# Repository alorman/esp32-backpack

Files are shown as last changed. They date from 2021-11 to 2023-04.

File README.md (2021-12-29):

# esp32-backpack
This board is designed to couple to the back of the the [DC Metro Map](https://github.com/alorman/dc-map-500x500) and drive the LEDs.  
This daughterboard-style design is to allow for rapid iteration and testing on the driving board, while keeping the large and expensive map PCB separate.

## Images
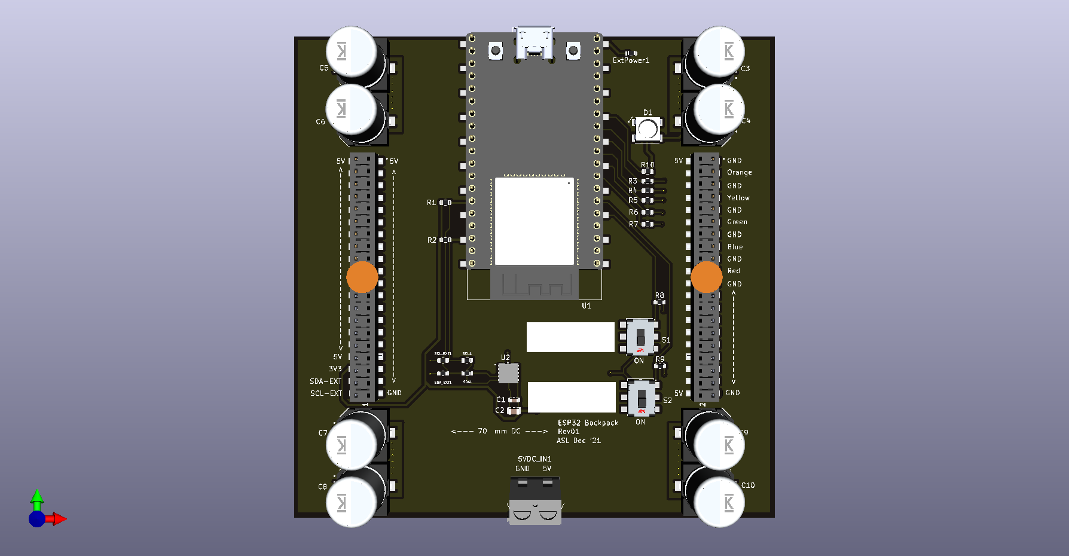
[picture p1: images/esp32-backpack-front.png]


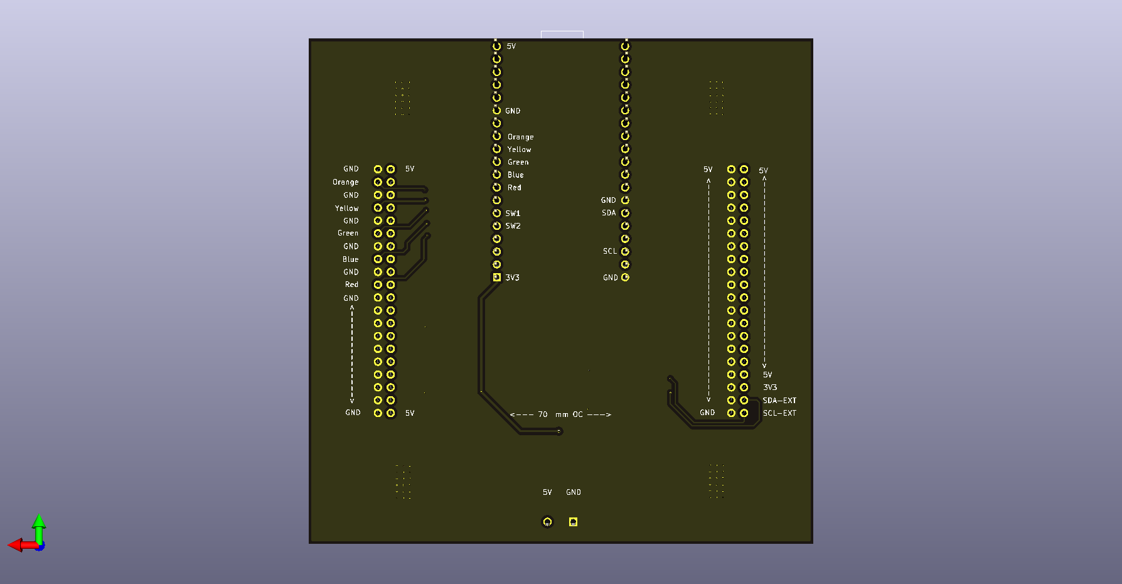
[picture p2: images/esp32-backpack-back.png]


## Schematic
[Schematic](exports/esp32-backpack-schematic.pdf)

## BOM
[Interactive BOM](exports/ibom.html)

## ESP Chipsets
ESP32 Chipsets come in about a zillion different configurations. To support the [code](https://github.com/alorman/dc_metro_map) you need a dual-core version. 

This board supports:
| Dev Kit Name | Module | Chipset | Cores | Flash | SPRAM | Notes |
|---|---|---|---|---|---|---|
| ESP32-DevKitCVE | ESP32-WROVER-E | ESP32-D0WD-V3 | 2 | 4 MB  | 8 MB  | Full Size PCB Antenna |
| ESP32-DevKitC-32E | ESP32-WROOM-32E  | ESP32-D0WD-V3 | 2 | 4 MB  | 4 MB  | Full Size PCB Antenna |
| ESP32-WROOM-32UE | ESP32­WROOM­32UE | ESP32-D0WD-V3 | 2 | 4 MB  | 4 MB  | u.FL Connector |
| HiLetgo ESP-WROOM-32 | ESP32-WROOM-32D  | ESP32-D0WD | 2 | 4 MB  | 4 MB  | NRND, Amazon |

Note: the HiLetGo (and likely other Amazonian boards) require a slight bending of the pins to fit.

## Fab Instructions
| | |
|---|---:|
| Height (mm) | 100 |
| Width (mm) | 100 |
| Layers | 2 |
| Thickness (mm) | 1.6 |
| Solder Mask | Black |
| Silkscreen | White |
| Copper Thickness  | 1 oz |
| Min Spacing | 8/8mil |
| Min Hole Size | 8mil |
| Via Process | Tented |
| Surface Treatment | HASL-Lead Free |
| Special Notes | None |

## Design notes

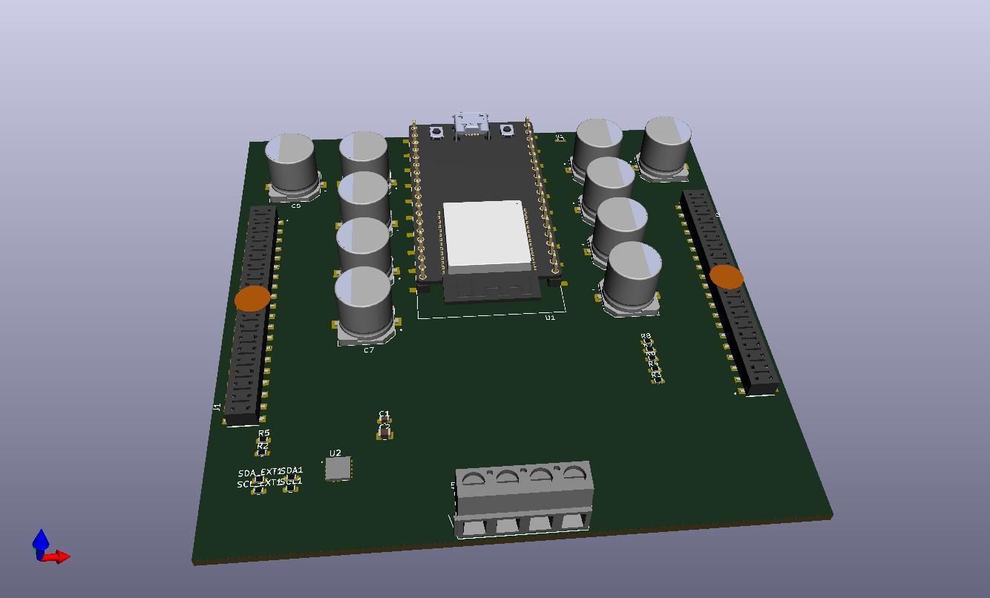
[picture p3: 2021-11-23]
ESP Backpack/ESP backpack.jpg

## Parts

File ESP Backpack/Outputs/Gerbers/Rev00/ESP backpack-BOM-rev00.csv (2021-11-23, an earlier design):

Id | Designator | Package | Quantity | Designation | Supplier and ref
1 | S1,S2 | 452403012014 | 2 | 452403012014
2 | D1 | LED_SK6812 | 1 | SK6812
3 | U1 | MODULE_ESP32-DEVKITC-32D | 1 | ESP32-DEVKITC-32D
4 | J1,J2 | SAMTEC_HLE-120-02-F-DV-BE-K | 2 | HLE-120-02-F-DV-BE-K
5 | 5VDC_IN1 | TE_282837-4 | 1 | 282837-4
6 | C6,C3,C4,C5,C7,C8,C9,C10,C11,C12,C13,C14 | CAP_EEE0JA102P | 12 | EEE0JA102P
7 | C1 | C_0603_1608Metric | 1 | 10uF
8 | C2 | C_0805_2012Metric | 1 | 0.1uF
9 | ExtPower1,SCL1,SCL_EXT1,SDA1,SDA_EXT1 | R_0603_1608Metric | 5 | 0ohm
10 | R2,R1,R8,R9 | R_0603_1608Metric | 4 | 10k
11 | R7,R6,R5,R4,R3,R10 | R_0603_1608Metric | 6 | 470
12 | U2 | XDCR_VCNL4010-GS08 | 1 | VCNL4010-GS08

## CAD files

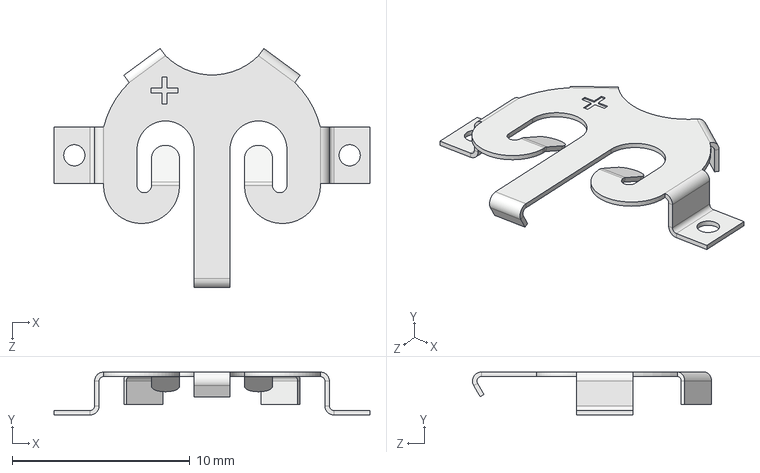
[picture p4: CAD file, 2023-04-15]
ESP Backpack/3d-Models/keystone-PN2894.STEP
17.8 x 2.42 x 13.5 mm

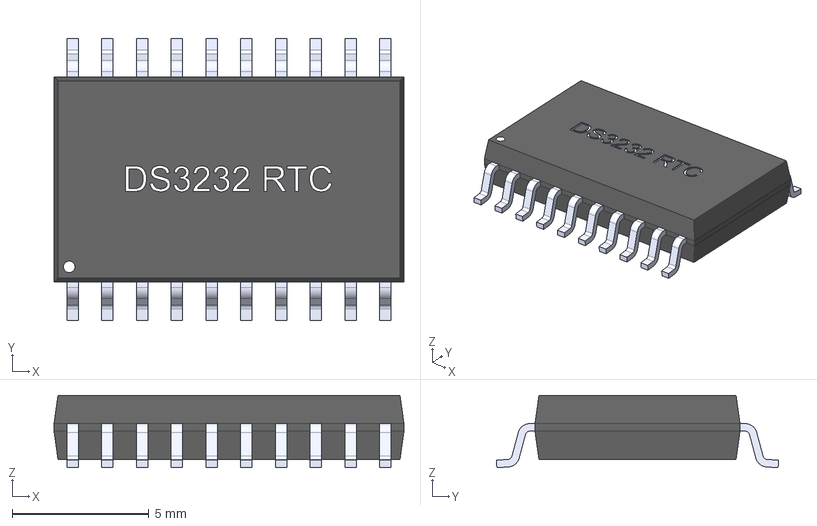
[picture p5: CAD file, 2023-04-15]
ESP Backpack/3d-Models/DS3232 RTC.step
12.8 x 10.3 x 2.65 mm
Komponente21
Komponente22
Komponente19
Komponente15
Komponente16
Komponente17
Komponente18
Komponente9
Komponente8
Komponente6
Komponente7
Komponente12
Komponente13
Komponente10
Komponente14
Komponente11
Komponente1
Komponente5
Komponente2
Komponente4
Komponente3

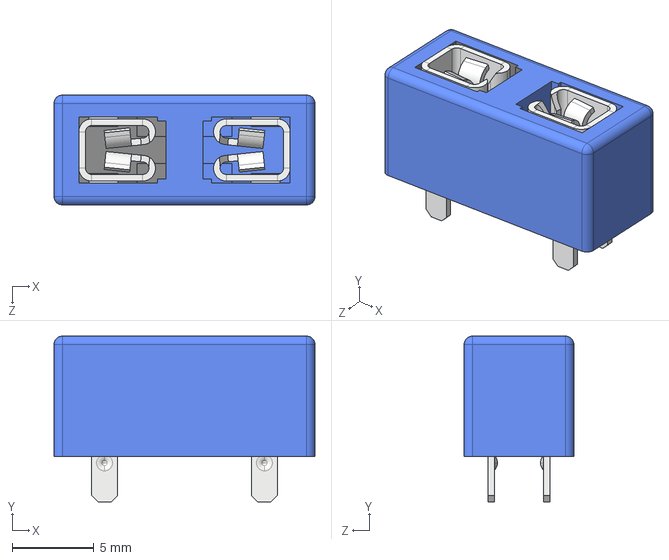
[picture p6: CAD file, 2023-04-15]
ESP Backpack/3d-Models/keystone-PN3568-15.STEP
16.0 x 10.2 x 6.73 mm

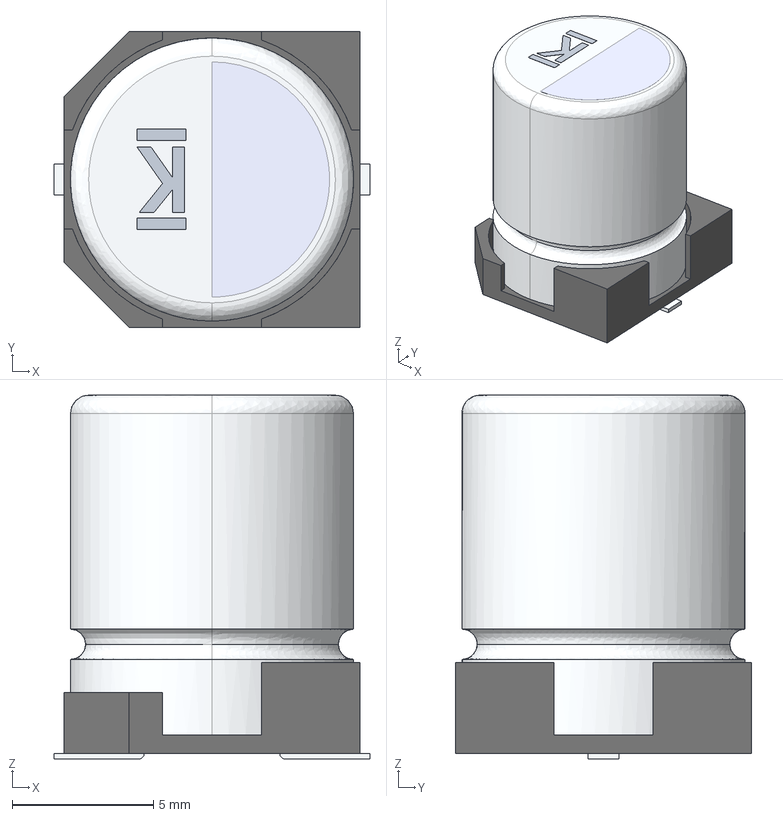
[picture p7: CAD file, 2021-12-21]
ESP Backpack/3d-Models/A765MU158M1ALAE014.step
11.2 x 10.5 x 12.9 mm

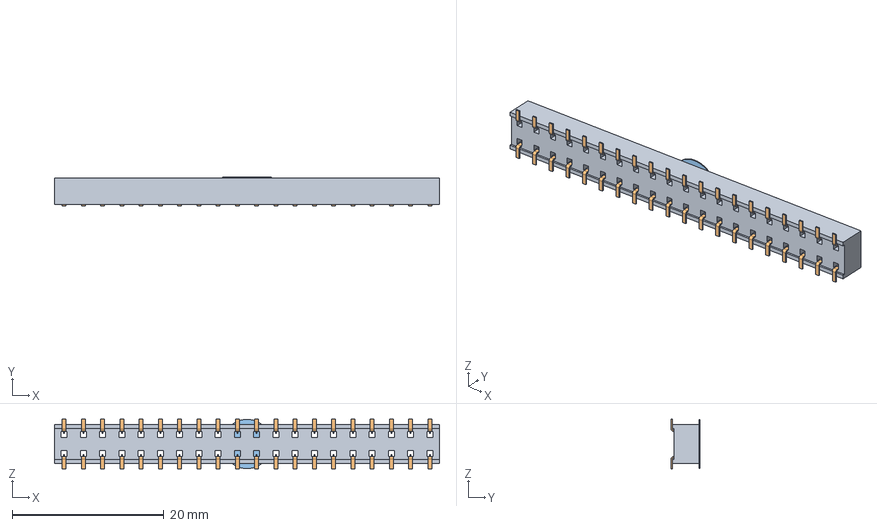
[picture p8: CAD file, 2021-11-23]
ESP Backpack/3d-Models/HLE-120-02-L-DV-K.step
50.8 x 3.78 x 6.58 mm
_HLE-120-02-DV_socket
_C-132-12-20-DV
_K-DOT-0.256-0.375-0.005_polyamide_pick

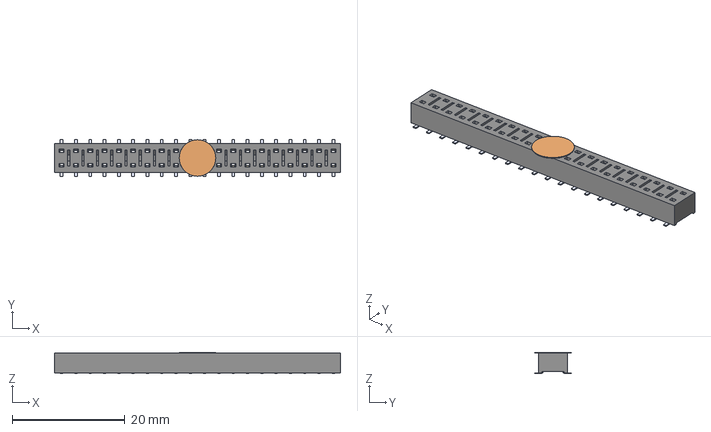
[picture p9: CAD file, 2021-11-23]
ESP Backpack/3d-Models/HLE-120-02-F-DV-BE-K--3DModel-STEP-56544.STEP
50.8 x 6.58 x 3.78 mm

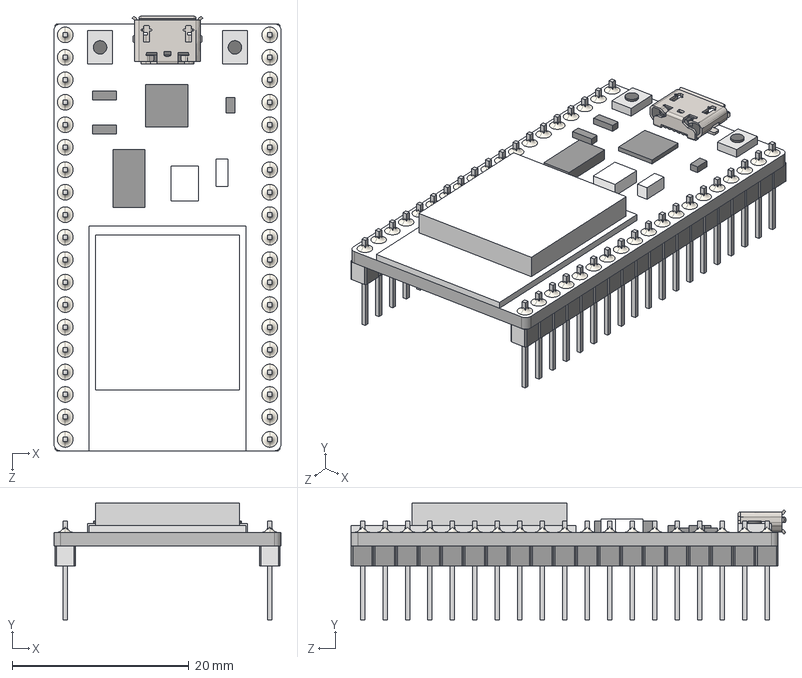
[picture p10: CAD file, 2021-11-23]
ESP Backpack/3d-Models/HiLetgo ESP32.STEP
25.7 x 13.2 x 49.1 mm
HiLetgo ESP32
molex_0473460001
PCB Button x 2
Pin Headers ESP32 x 2

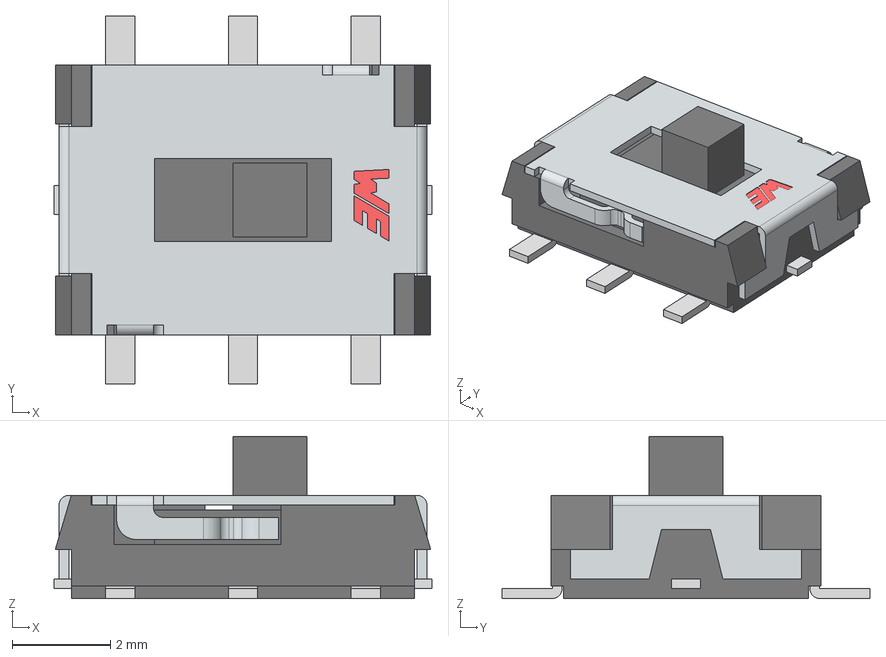
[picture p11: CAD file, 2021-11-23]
ESP Backpack/3d-Models/Download_STP_452403012014 (rev1).stp
7.70 x 7.50 x 3.30 mm
Base
Actuator
cover

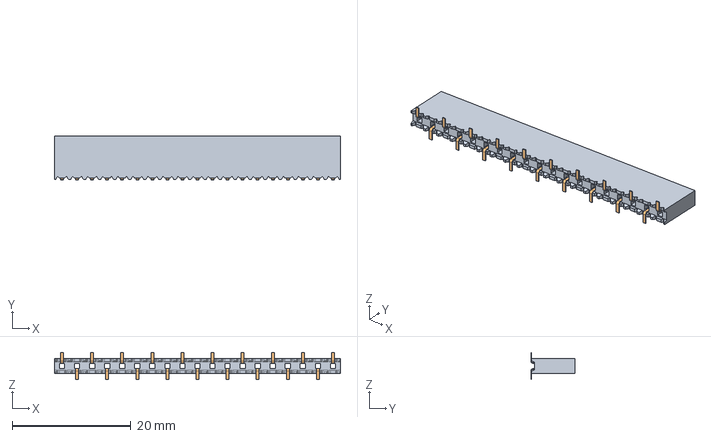
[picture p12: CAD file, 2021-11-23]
ESP Backpack/3d-Models/SSM-119-L-SV.step
48.3 x 7.49 x 4.57 mm
_SSM-119-L-SV_body
_C-95-0219

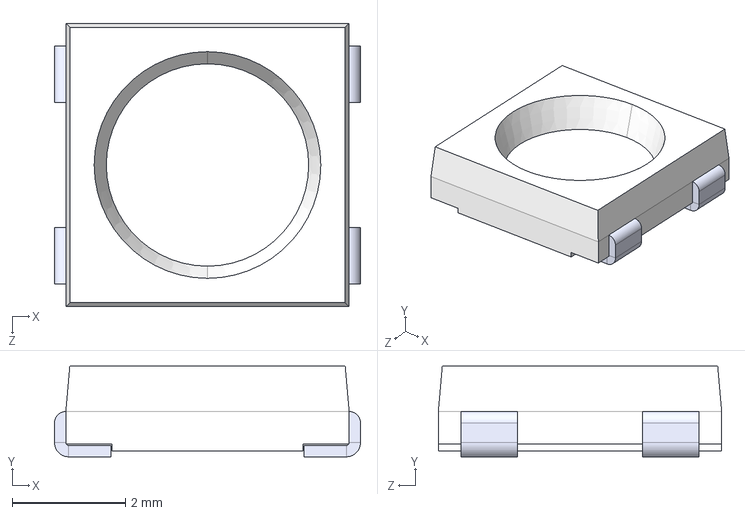
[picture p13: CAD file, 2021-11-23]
ESP Backpack/3d-Models/SK6812.step
5.40 x 1.60 x 5.00 mm

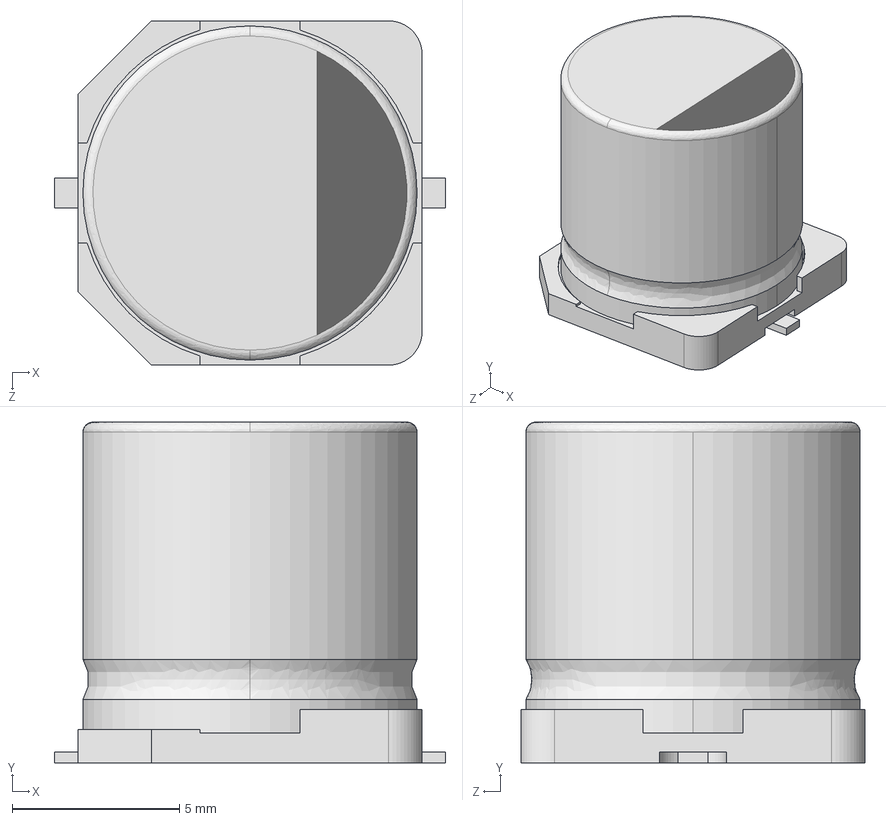
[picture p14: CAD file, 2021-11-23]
ESP Backpack/3d-Models/EEE0JA102P.step
11.7 x 10.2 x 10.3 mm

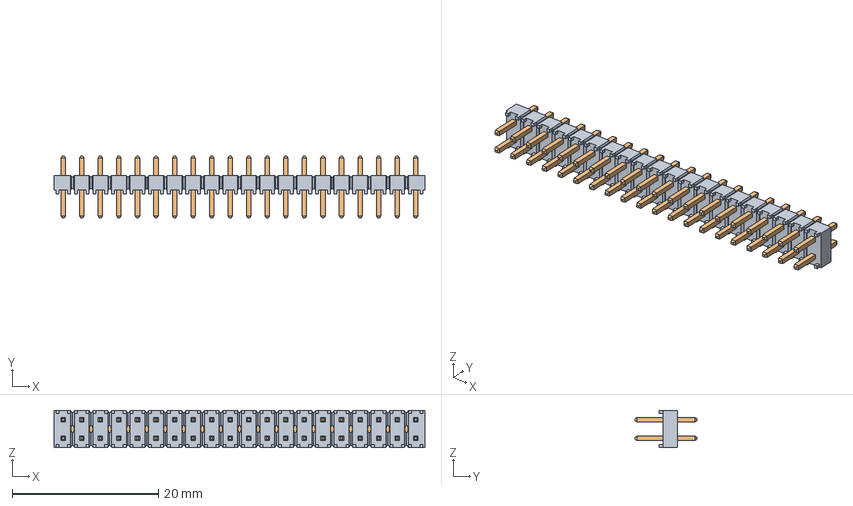
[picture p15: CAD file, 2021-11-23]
ESP Backpack/3d-Models/TSW-120-05-G-D.step
50.8 x 8.51 x 5.08 mm
_TSW-120-05-G-D_body
_T-1S6-21-TSW-1-05-20-D

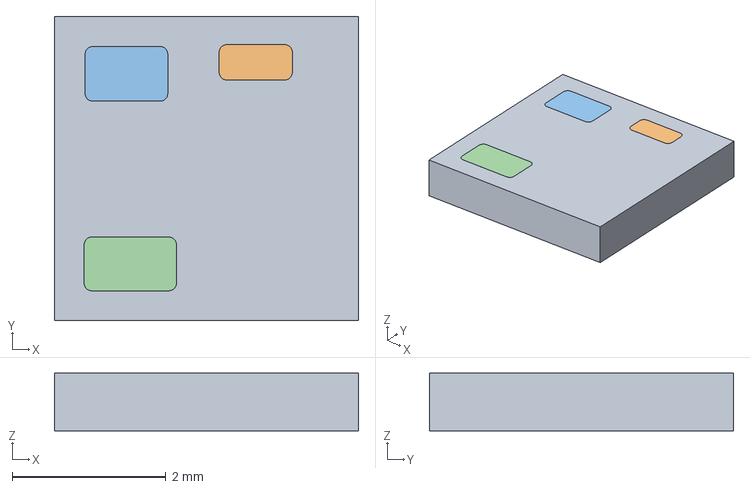
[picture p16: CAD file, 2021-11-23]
ESP Backpack/3d-Models/VCNL4010.stp
3.95 x 3.95 x 0.75 mm

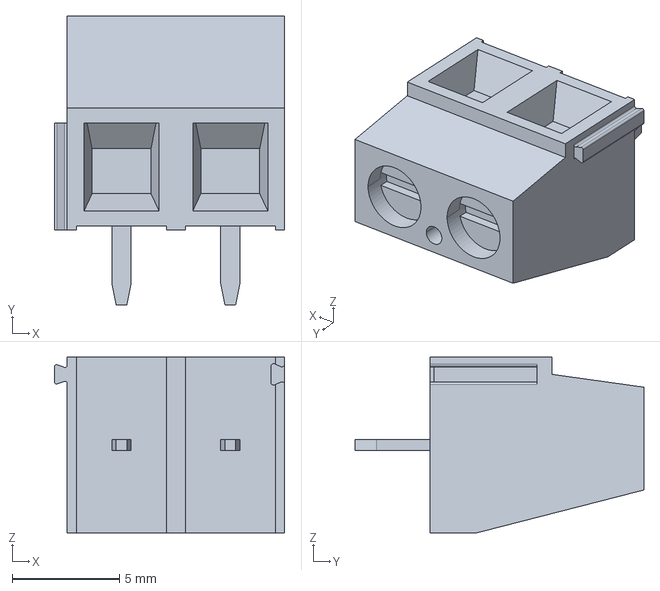
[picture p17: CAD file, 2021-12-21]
ESP Backpack/3d-Models/282837-2.step
10.8 x 13.5 x 8.20 mm

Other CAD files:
ESP Backpack/3d-Models/EEE0JA102P.stp

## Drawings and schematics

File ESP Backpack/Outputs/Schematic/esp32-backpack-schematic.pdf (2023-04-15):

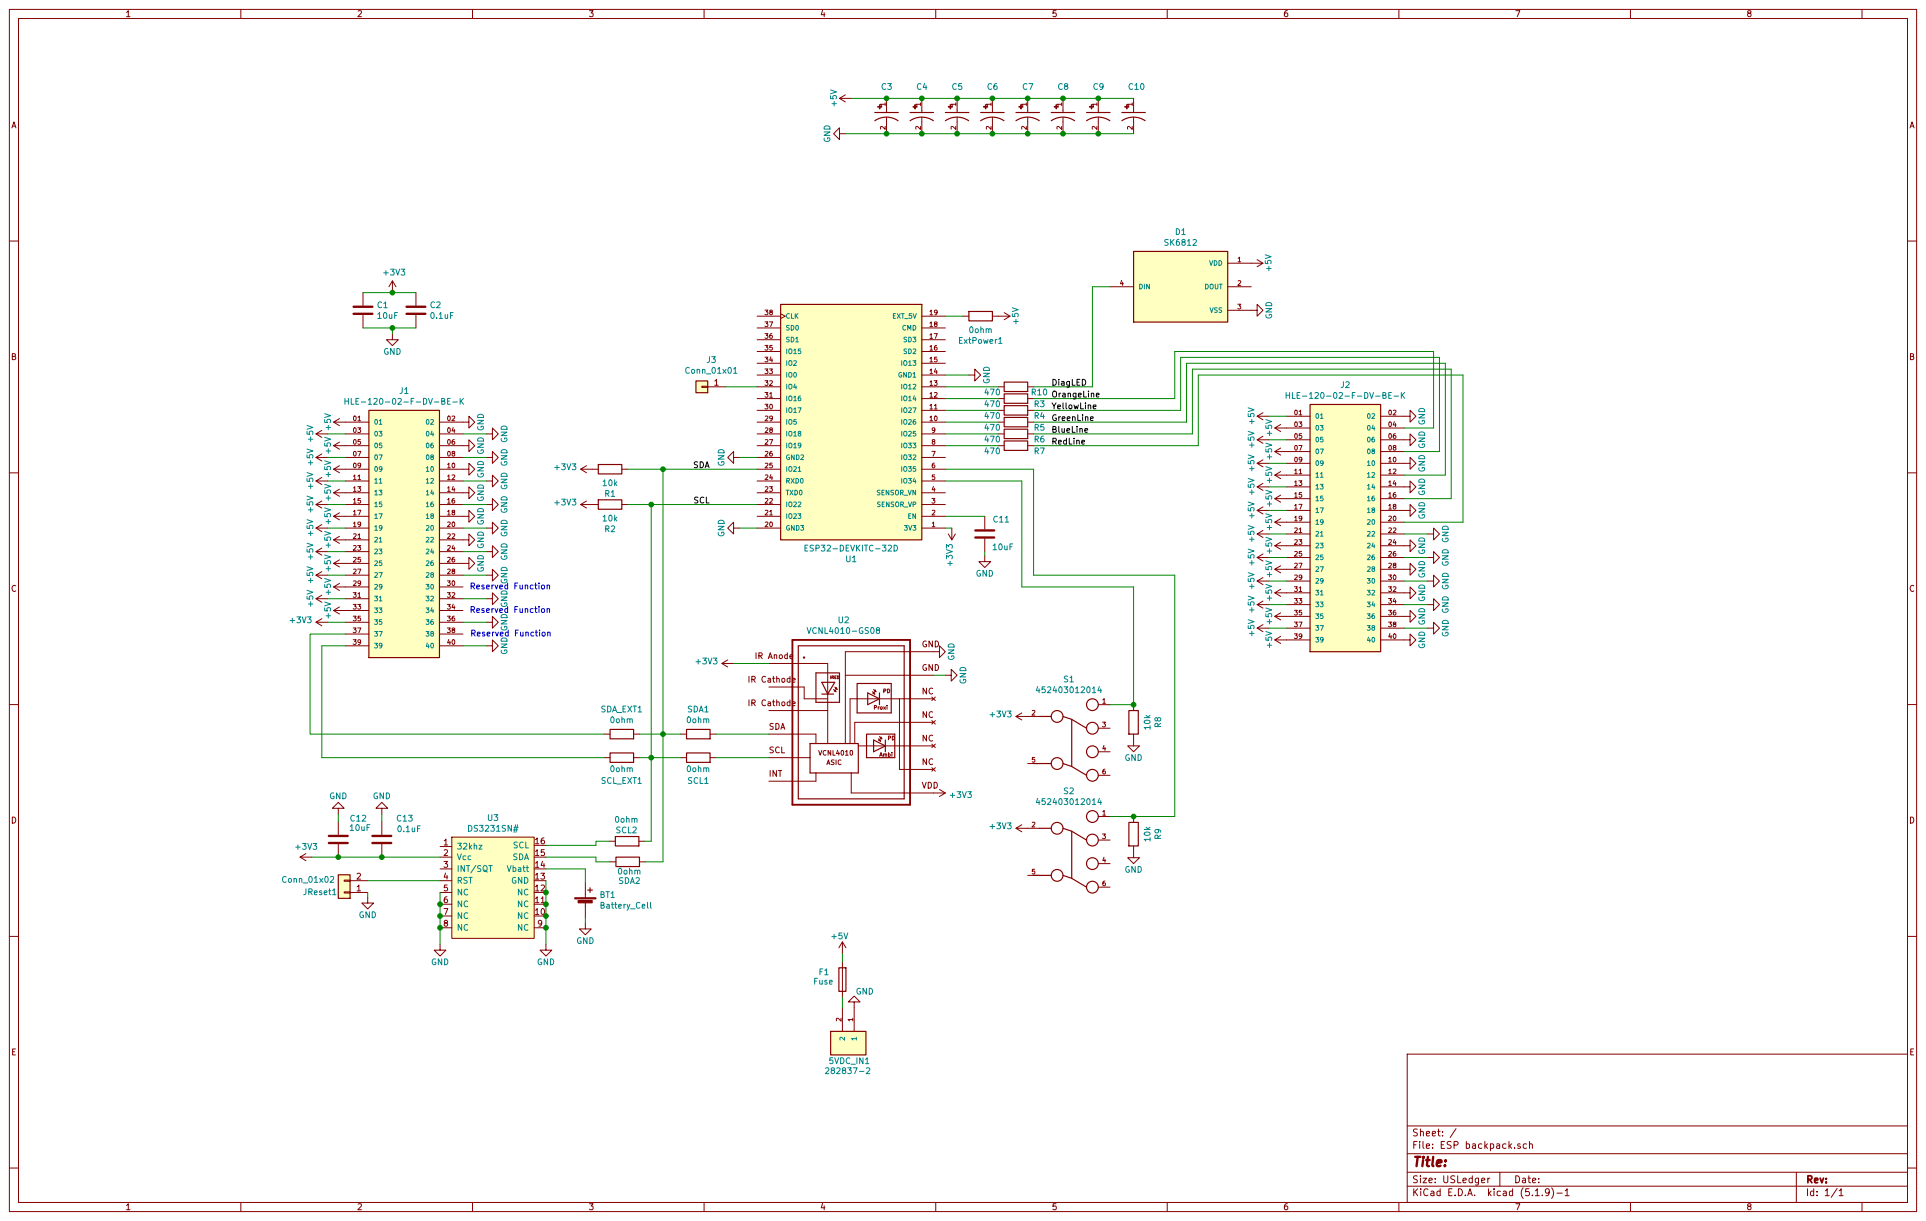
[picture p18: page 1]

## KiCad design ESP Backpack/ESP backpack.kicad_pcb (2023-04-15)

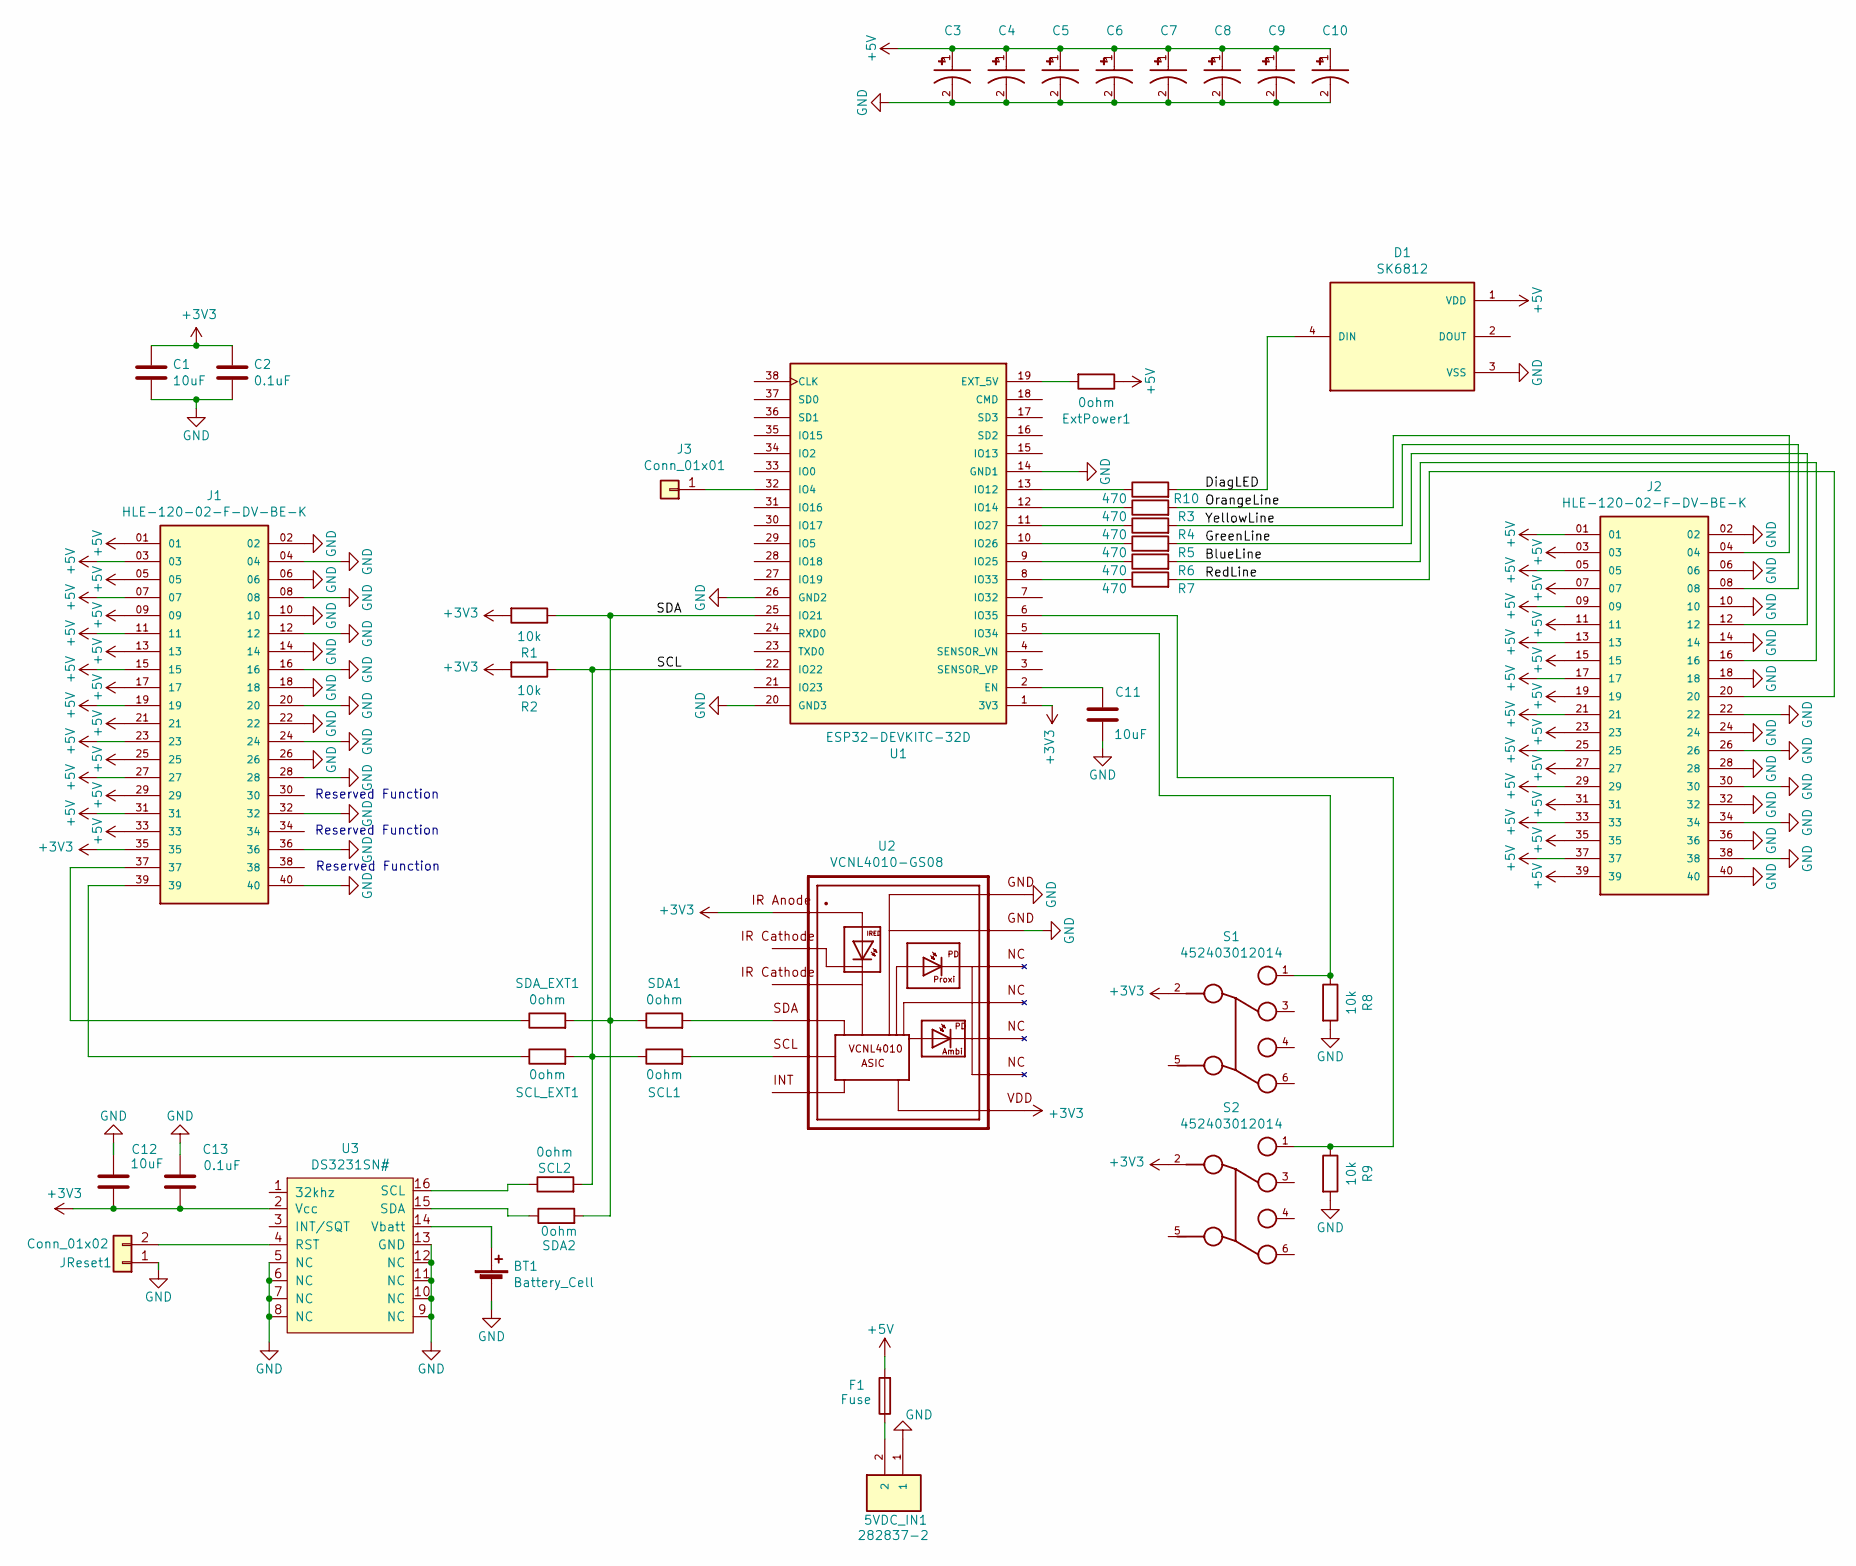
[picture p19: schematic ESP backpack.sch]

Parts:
5VDC_IN1: 282837-2; TE_282837-2
BT1: Battery_Cell; Keystone_2894
C1, C11, C12: 10uF; C_0603_1608Metric
C2: 0.1uF; C_0805_2012Metric
C3, C4, C5, C6, C7, C8, C9, C10: A765MU158M1ALAE014; CAP_EEE0JA102P
C13: 0.1uF; C_0603_1608Metric
D1: SK6812; LED_SK6812; PARTREV 03
ExtPower1: 0ohm; R_0603_1608Metric
F1: Fuse; Keystone-3658
J1, J2: HLE-120-02-F-DV-BE-K; SAMTEC_HLE-120-02-F-DV-BE-K
J3: Conn_01x01; PinHeader_1x01_P2.54mm_Vertical
JReset1: Conn_01x02; PinHeader_1x02_P2.54mm_Vertical
R1, R2, R8, R9: 10k; R_0603_1608Metric
R3, R4, R5, R6, R7, R10: 470; R_0603_1608Metric
S1, S2: 452403012014
SCL1, SCL2: 0ohm; R_0603_1608Metric
SCL_EXT1: 0ohm; R_0603_1608Metric
SDA1, SDA2: 0ohm; R_0603_1608Metric
SDA_EXT1: 0ohm; R_0603_1608Metric
U1: ESP32-DEVKITC-32D; MODULE_ESP32-DEVKITC-32D; PARTREV 4
U2: VCNL4010-GS08; XDCR_VCNL4010-GS08; PARTREV 1.6
U3: DS3231SN#; SOIC-16W_7.5x10.3mm_P1.27mm

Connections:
+3V3: C1.1, C2.1, C12.2, C13.2, J1.35, R1.2, R2.2, S1.2, S2.2, U1.1 (3V3), U2.1, U2.7, U3.2 (Vcc)
+5V: C3.1, C4.1, C5.1, C6.1, C7.1, C8.1, C9.1, C10.1, D1.1 (VDD), ExtPower1.1, F1.2, J1.01, J1.03, J1.05, J1.07, J1.09, J1.11, J1.13, J1.15, J1.17, J1.19, J1.21, J1.23, J1.25, J1.27, J1.29, J1.31, J1.33, J2.01, J2.03, J2.05, J2.07, J2.09, J2.11, J2.13, J2.15, J2.17, J2.19, J2.21, J2.23, J2.25, J2.27, J2.29, J2.31, J2.33, J2.35, J2.37, J2.39
/BlueLine: J2.16, R6.2
/DiagLED: D1.4 (DIN), R10.2
/GreenLine: J2.12, R5.2
/OrangeLine: J2.04, R3.2
/RedLine: J2.20, R7.2
/SCL: R2.1, SCL1.1, SCL2.2, SCL_EXT1.2, U1.22 (IO22)
/SDA: R1.1, SDA1.1, SDA2.2, SDA_EXT1.2, U1.25 (IO21)
/YellowLine: J2.08, R4.2
GND: 5VDC_IN1.1, BT1.2 (-), C1.2, C2.2, C3.2, C4.2, C5.2, C6.2, C7.2, C8.2, C9.2, C10.2, C11.2, C12.1, C13.1, D1.3 (VSS), J1.02, J1.04, J1.06, J1.08, J1.10, J1.12, J1.14, J1.16, J1.18, J1.20, J1.22, J1.24, J1.26, J1.28, J1.32, J1.36, J1.40, J2.02, J2.06, J2.10, J2.14, J2.18, J2.22, J2.24, J2.26, J2.28, J2.30, J2.32, J2.34, J2.36, J2.38, J2.40, JReset1.1, R8.2, R9.2, U1.14 (GND1), U1.20 (GND3), U1.26 (GND2), U2.12, U2.13, U3.5 (NC), U3.6 (NC), U3.7 (NC), U3.8 (NC), U3.9 (NC), U3.10 (NC), U3.11 (NC), U3.12 (NC), U3.13 (GND)
unnamed: 5VDC_IN1.2, F1.1
unnamed: BT1.1 (+), U3.14 (Vbatt)
unnamed: C11.1, U1.2 (EN)
unnamed: ExtPower1.2, U1.19 (EXT_5V)
unnamed: J1.37, SDA_EXT1.1
unnamed: J1.39, SCL_EXT1.1
unnamed: J3.1, U1.32 (IO4)
unnamed: JReset1.2, U3.4 (RST)
unnamed: R3.1, U1.12 (IO14)
unnamed: R4.1, U1.11 (IO27)
unnamed: R5.1, U1.10 (IO26)
unnamed: R6.1, U1.9 (IO25)
unnamed: R7.1, U1.8 (IO33)
unnamed: R8.1, S1.1, U1.5 (IO34)
unnamed: R9.1, S2.1, U1.6 (IO35)
unnamed: R10.1, U1.13 (IO12)
unnamed: SCL1.2, U2.5
unnamed: SCL2.1, U3.16 (SCL)
unnamed: SDA1.2, U2.4
unnamed: SDA2.1, U3.15 (SDA)

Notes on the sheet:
Reserved Function

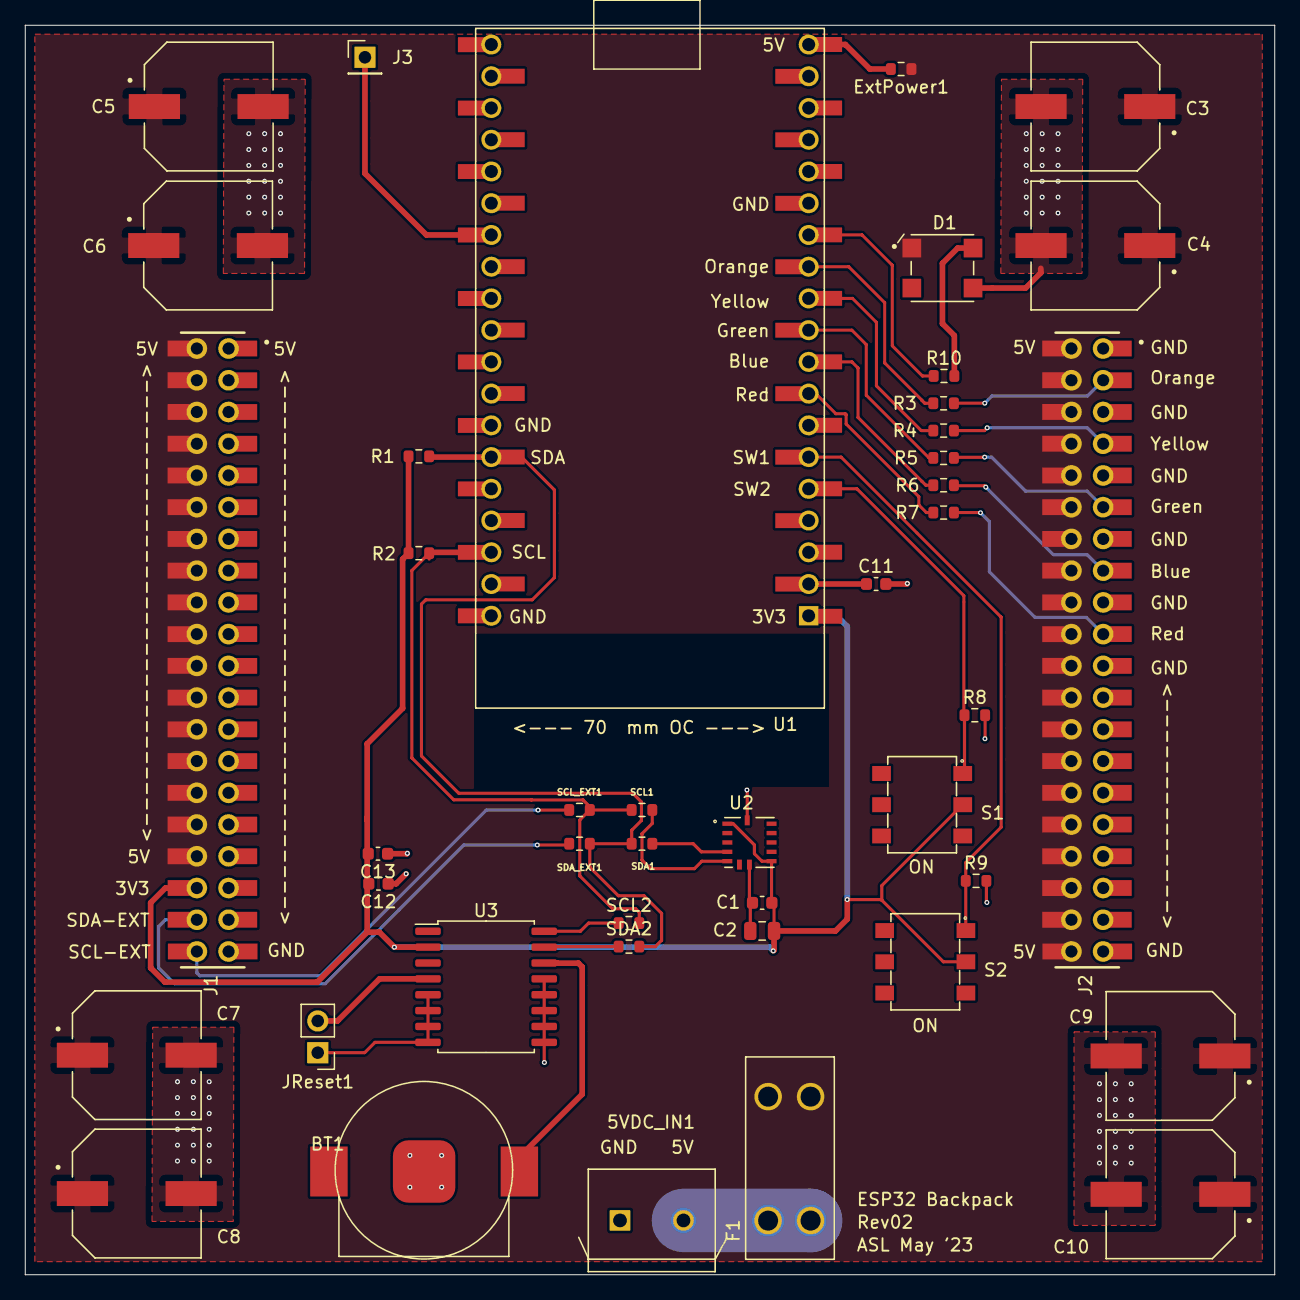
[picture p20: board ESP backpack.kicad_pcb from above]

Board: 2 copper layers, 100.0 x 100.0 mm, 43 parts (0 on the bottom side), 31 nets.

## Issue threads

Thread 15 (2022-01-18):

Add 10uF cap between EN and GND for auto reset

alorman, 2022-01-18:

Closed 2023-04-15.

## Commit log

2021-11-23 add files to baseline to rev00 as sent to fab
    [282837-4.step, Download_STP_452403012014 (rev1).stp, EEE0JA102P.step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]
2021-12-17 Re-org files for relative pathing, change extensions for globally unique names
    [282837-4.step, Download_STP_452403012014 (rev1).stp, EEE0JA102P.step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]
2021-12-19 change paths to sort to top of list
    [282837-4.step, Download_STP_452403012014 (rev1).stp, EEE0JA102P.step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]
2021-12-19 change 3d models to relative
    [ESP backpack.kicad_pcb]
2021-12-20 add VCNL step files
    [ESP backpack.kicad_pcb]
2021-12-20 fix wurth switches in #13
    [ESP backpack.kicad_pcb]
2021-12-21 edit all libs and footprints into single libraries and files. Issue fixes
    [282837-2.step, 282837-4.step, A765MU158M1ALAE014.step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]
2021-12-22 change zones to include pad specific overrides
    [ESP backpack-BOM-rev00.csv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]
2021-12-22 edit weird fill issue
    [ESP backpack-B_CrtYd.gbr, ESP backpack-B_Cu.gbr, ESP backpack-B_Mask.gbr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]
2023-02-01 reorg to more standard file tree
    [282837-2.step, A765MU158M1ALAE014.step, Download_STP_452403012014 (rev1).stp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]
2023-04-15 reorg into more traditional arrangement
    [282837-2.step, A765MU158M1ALAE014.step, Download_STP_452403012014 (rev1).stp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]
2023-04-15 fixes #17, #18, #15 and adds RTC
    [DS3232 RTC.step, ESP backpack.kicad_pcb, ESP backpack.sch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]
2023-04-15 add outputs
    [ESP backpack-B_CrtYd.gbr, ESP backpack-B_Cu.gbr, ESP backpack-B_Mask.gbr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]

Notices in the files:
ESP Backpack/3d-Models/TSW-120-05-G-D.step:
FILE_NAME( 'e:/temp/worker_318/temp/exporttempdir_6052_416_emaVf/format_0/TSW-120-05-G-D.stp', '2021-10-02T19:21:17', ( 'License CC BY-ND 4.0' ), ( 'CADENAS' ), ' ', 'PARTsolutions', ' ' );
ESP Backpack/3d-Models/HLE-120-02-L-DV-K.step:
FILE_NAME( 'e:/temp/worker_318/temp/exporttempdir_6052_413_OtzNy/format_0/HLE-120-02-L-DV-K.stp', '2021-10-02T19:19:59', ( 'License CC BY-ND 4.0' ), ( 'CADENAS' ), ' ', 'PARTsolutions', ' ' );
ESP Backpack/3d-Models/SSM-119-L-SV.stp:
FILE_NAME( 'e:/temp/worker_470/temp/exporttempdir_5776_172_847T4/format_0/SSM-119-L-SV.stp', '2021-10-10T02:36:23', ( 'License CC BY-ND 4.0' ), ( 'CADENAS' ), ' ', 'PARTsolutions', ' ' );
